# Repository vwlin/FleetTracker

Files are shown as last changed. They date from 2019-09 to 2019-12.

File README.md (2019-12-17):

# FleetTracker
Dugan's Dogs capstone project! Solar-powered vehicle tracking with real-time map visualization.

Setup instructions:
A and B necessary to complete setup

A. CCS Setup
1. Create new CCS project
2. In New CCS Project window, select MSP430F5529 for target and choose to create an empty project (without main.c)
3. In Project Explorer, right click on project, go to Add Files
4. Select relevant files and choose Link to Files (ensures compatibility with Git)

B. Adding "driverlib" folder
1. In Project Explorer, right click on project, go to Import > Import
2. In Import window, go to General > File System, then Next
3. Browse and select the directory (DirX) one step above driverlib folder, then OK
4. Dropdown DirX and check driverlib (not DirX), then Finish

C. Creating new files
1. Create file in local repo, but don't create it using CCS (i.e. use file explorer, terminal, etc)
2. Link to file in CCS (see A. 3-4)

TeraTerm download and Tips:
Download latest version of TeraTerm [here](https://ttssh2.osdn.jp/index.html.en).
To use TeraTerm with the firmware:
1. Open Tera Term and select Serial. Select the appropriate USB Serial Port for the port. Click OK.
2. If the device does not show up as a serial port, the proper drivers may not be installed and can be found [here](https://www.ftdichip.com/FTDrivers.htm).
3. Go to Setup > Serial Port. In the dropdown menu for Speed, select the appropriate baudrate. Click OK.
4. Go to Setup > Terminal and select Local echo. In the Coding-receive and Coding-transmit dropdown menus, select "UTF-8". Click OK.
5. TeraTerm is ready to be used

UI Setup
1. If using Windows, we recommend using Anaconda to install all Python packages, found here: https://www.anaconda.com/distribution/#windows
2. The following packages are required for our UI to display correctly:
* serial:      conda install -c anaconda pyserial
* folium:      conda install -c conda-forge folium
* matplotlib:  conda install -c conda-forge matplotlib
* selenium:    conda install -c conda-forge selenium
* pyautogui:   conda install -c conda-forge pyautogui
3. To run the program:
* open an Anaconda terminal
* cd into the project directory
* run in the terminal:
	* python main.py <COM#>

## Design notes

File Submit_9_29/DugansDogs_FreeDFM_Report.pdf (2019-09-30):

What FreeDFM found on your design

# Show Stoppers

## We Found None!

# Problems Automatically Fixed

Insufficient Silkscreen Line Width (494 violations) (https://www.freedfm.com/freedfm/0027733205411211/results/silkscreen_line_width.htm) | 1 (https://www.freedfm.com/freedfm/0027733205411211/results/silkscreen_line_width.htm#1) 2 (https://www.freedfm.com/freedfm/0027733205411211/results/silkscreen_line_width.htm#2) 3 (https://www.freedfm.com/freedfm/0027733205411211/results/silkscreen_line_width.htm#3) 4 (https://www.freedfm.com/freedfm/0027733205411211/results/silkscreen_line_width.htm#4) 5 (https://www.freedfm.com/freedfm/0027733205411211/results/silkscreen_line_width.htm#5)

Advanced
Circuits

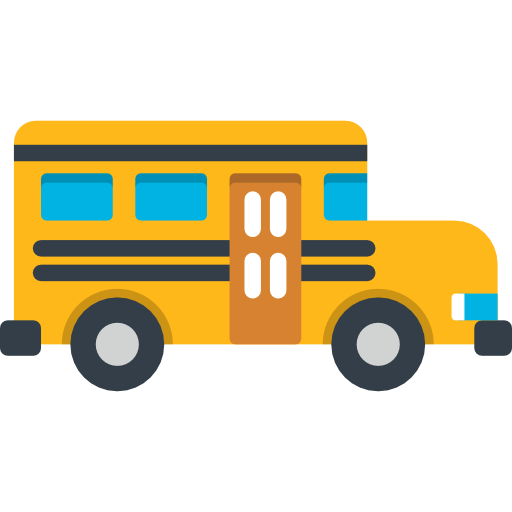
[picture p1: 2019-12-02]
UI/bus.png

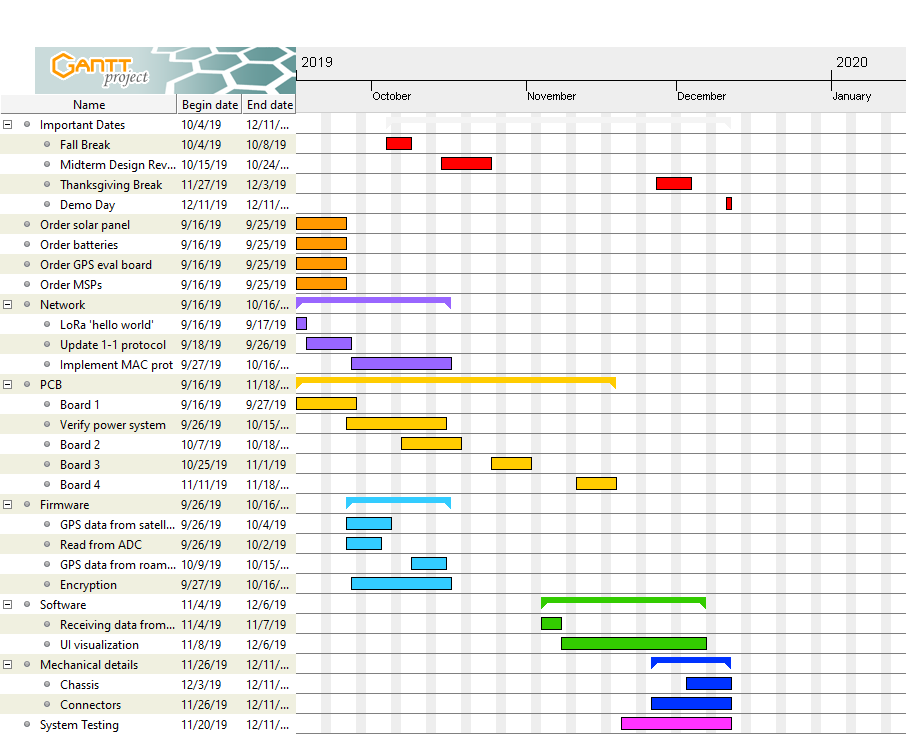
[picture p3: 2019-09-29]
Gantt Chart/CapstoneGantt.png

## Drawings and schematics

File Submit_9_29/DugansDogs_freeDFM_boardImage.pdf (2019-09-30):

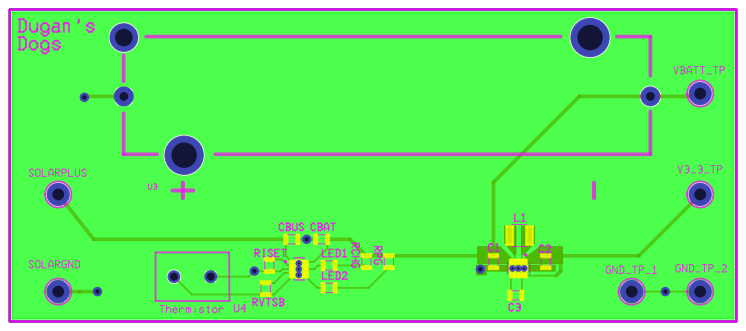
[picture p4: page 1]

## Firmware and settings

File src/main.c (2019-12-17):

#include <msp430.h>
#include <stdlib.h>
#include <string.h>
#include <stdio.h>
#include <stdint.h>

#include "SPI.h"
#include "LORA.h"
#include "test.h"
#include "protocol.h"
#include "UART.h"
#include "help.h"
#include "clock.h"
#include "configure.h"
#include "gps.h"
#include "timerA.h"

/* CHOOSE ONE
 *
 * ROAMING_NODE
 * HOME_NODE
 * TEST
 */

//#define ROAMING_NODE
#define HOME_NODE
//#define TEST

// TODO: move to protocol.h file somehow
uint16_t backoffSec[8] = {1, 2, 4, 8, 16, 32, 64, 128}; // Exponential back-off lookup table for MAC protocol, for a = 2 seconds

uint8_t year, month, day, hour, min, sec;
int32_t latitude, longitude;

void main(void){
    WDTCTL = WDTPW | WDTHOLD;   // Stop watchdog timer

    Configure_Clock();
    Configure_UART();
    Configure_SPI_LORA();
    Configure_LORA();

    #ifdef ROAMING_NODE
    Configure_SPI_GPS();
    Configure_GPS();
    Configure_TimerA();
    #endif

    unsigned char configPacket[28];
    unsigned char navPacket[8];

    // Construct data request and configuration packets for GPS
    ublox_configure_spi_port(configPacket);
    configure_ublox_poll(navPacket, 0x01, 0x07);

    unsigned char ublox_input_buffer[100];
    unsigned char payload[92];
    int i;

    #ifdef TEST
    volatile uint8_t passLORA = testLORA();
    #endif

    // Reset LoRa chip
    LORA_Reset();

    #ifndef TEST
    // Check for errors in the LoRa chip
    uint16_t errors = LORA_GetDeviceErrors();
    if(errors != 0){
        printf("\r\nErrors found. Restart the device.");
        while(1);
    }
    #endif

    // Configure communications
    LORA_SetStandby(STDBY_RC);
    LORA_SetPacketType(PACKET_TYPE_LORA);
    LORA_SetRfFrequency(CENTER_FREQUENCY); // Configurable in configure.h
    LORA_SetPaConfig(0x04, 0x07, PA_CONFIG_1262);
    LORA_SetTxParams(22, SET_RAMP_200U);
    LORA_SetModulationParams(0, 0, 0, SPREADING_FACTOR, CODING_RATE, LDR_OPT_ENABLE, BANDWIDTH); // Configurable in configure.h
    LORA_SetPacketParams(0, 0, 0, 0, 0, HEADER_MODE, IQ_MODE, PREAMBLE_LENGTH, PAYLOAD_LENGTH, CRC_ENABLE); // Configurable in configure.h
    LORA_SetBufferBaseAddress(0x00, 0x00); // Use all 256 bytes for the current mode
    LORA_SetCadParams(CAD_ON_8_SYMB, 25, 6, CAD_ONLY, 0); // Perform CAD operation, then return to STBY_RC mode

    // Set LoRa Sync word MSB and LSB
    uint8_t regData[2] = {0x14, 0x24};
    LORA_WriteRegister(0x0740, regData, 2);

    // Configure hardware
    LORA_SetRegulatorMode(REGULATOR_DCDC_LDO); // Use DC-DC regulator
    SET_ANT_SW; // Set RF switch to pass through TX output
    LORA_SetDIO2AsRfSwitchCtrl(DIO2_AS_SWITCH); // Set RF switch to pass through TX output

    #ifdef TEST
    volatile uint8_t passLORA = testLORA();

    // Select on of the following tests at a time
    //LORA_SetTxContinuousWave();
    LORA_SetTxInfinitePreamble();
    //volatile uint8_t passRF = testReceiveOneFrame();  // Select either this line or testTransmitOneFrame

    while(1){
        //testTransmitOneFrame();   // Select either this line or testReceiveOneFrame
    }
    #endif

    uint8_t data[PAYLOAD_LENGTH] = {0};
    uint8_t status = 0;

    // RDT protocol related variables
    uint8_t seqNumber[1] = {0}; // Start with a sequence number of 0

    // MAC protocol related variables
    uint16_t channelStatus;
    uint8_t numAttempts;

    while(1){
        #ifdef ROAMING_NODE
            // Fill variables from payload
            for(i = 0; i<92; i++){
                payload[i] = ublox_input_buffer[i + 6];
            }

            // Populate variables with bits from payload
            year = (uint8_t)(payload[4]) + (uint8_t)(payload[5] << 8);
            month = (uint8_t)payload[6];
            day = (uint8_t)payload[7];
            hour = (uint8_t)payload[8] - 5; // Subtract 5 to get our local time
            min = (uint8_t)payload[9];
            sec = (uint8_t)payload[10];
            longitude = ((int32_t) payload[27]) << 24 | ((int32_t) payload[26]) << 16 |
                    ((int32_t) payload[25]) << 8 | (int32_t) (payload[24]);
            latitude = ((int32_t) payload[31]) << 24 | ((int32_t) payload[30]) << 16 |
                            ((int32_t) payload[29]) << 8 | (int32_t) (payload[28]);

            // Clear input buffer
            for(i = 0; i<100; i++){
                ublox_input_buffer[i] = 0;
            }

            // Send configuration packet to GPS
            SPI_SendPacket_GPS(configPacket, 28);

            // Wait until data received is nonzero
            while(ublox_input_buffer[0] == 0) {
                SPI_ReceivePacket_GPS(ublox_input_buffer,100);
            }

            // Wait until data received starts with 0xB5 (UBX Protocol)
            while((ublox_input_buffer[0] != 0xb5)){

                // Send data request
                SPI_SendPacket_GPS(navPacket,8);
                for(i = 0; i<100; i++) ublox_input_buffer[i]=0;

                // Wait until data received is nonzero
                while(ublox_input_buffer[0] == 0) {
                    SPI_ReceivePacket_GPS(ublox_input_buffer,100);
               }
            }

            // Fill empty locations with zeros
            for(i = 0; i < PAYLOAD_LENGTH; i++){
                data[i] = 0;
            }

            // Fill payload, leaving first bit empty for sequence number
            data[0] = (uint8_t)((DEVICE_ID & 0x1FC0) >> 6);
            data[1] = (uint8_t)((DEVICE_ID & 0x003F) << 2);
            // Optional: data[1] | first 2 bits of ADC readings
            data[4] = (uint8_t)((latitude & 0xC0000000) >> 30); // Optional: OR with end of ADC readings
            data[5] = (uint8_t)((latitude & 0x3FC00000) >> 22);
            data[6] = (uint8_t)((latitude & 0x003FC000) >> 14);
            data[7] = (uint8_t)((latitude & 0x00003FC0) >> 6);  // In python, read latitude values and shift left 6
            data[8] = (uint8_t)((longitude & 0xFF000000) >> 24);
            data[9] = (uint8_t)((longitude & 0x00FF0000) >> 16);
            data[10] = (uint8_t)((longitude & 0x0000FF00) >> 8);
            data[11] = (uint8_t)(longitude & 0x000000C0); // In python, read longitude values and shift left 6
            data[11] |= (uint8_t)((day & 0x1F) << 1);
            data[11] |= (uint8_t)((month & 0x08) >> 3);
            data[12] = (uint8_t)((month & 0x07) << 5);
            data[12] |= (uint8_t)(hour & 0x1F);
            data[13] = (uint8_t)((min & 0x3F) << 2);
            data[13] |= (uint8_t)((sec & 0x30) >> 4);
            data[14] = (uint8_t)((sec & 0x0F) << 4);

            printf("\r\nDevice %d", DEVICE_ID);
            printf("\r\nPayload: ");
            for(i = 0; i < PAYLOAD_LENGTH; i++){
                printf("%x ", data[i]);
            }

            // Check for channel activity and repeat if activity detected
            numAttempts = 0;
            channelStatus = 0x0180;
            while( ( channelStatus & 0x0100) && (numAttempts <= GIVEUP_MAC) ){ // Repeat as long as CAD has been detected
                LORA_SetDioIrqParams(0x0180, 0x0000, 0x0000, 0x0000); // Enable CadDone and CadDetected IRQs
                LORA_SetCAD(); // Begin CAD
                while( !LORA_GetIrqStatus() ); // Poll CadDone IRQ
                channelStatus = LORA_GetIrqStatus(); // Check CadDetected IRQ
                LORA_ClearIrqStatus(0x0180); // Clear CadDone and CadDetected
                numAttempts++;
                if(channelStatus & 0x0100){ // If activity detected, wait
                    delay_s(backoffSec[numAttempts]);
                }
                // Print out results
                if(channelStatus & 0x0100)
                    printf("\r\nChannel activity detected, attempt %d", numAttempts);
                else
                    printf("\r\nNo channel activity detected, attempt %d", numAttempts);
            }

            // Proceed based on results of MAC checks
            if(numAttempts > GIVEUP_MAC){ // Activity detected multiple times in a row
                printf("\r\nGave up");
            }
            else if( !(channelStatus & 0x0100) ){ // No activity detected
                printf("\r\nSending data");
                status = Roamer_EstablishConnection(data, PAYLOAD_LENGTH, seqNumber);
            }

            // Sleep for sleepTime seconds
            // Enter LPM1 with SCLK on (SMCLKOFF = 0): ACLK and SCLK on, GPIO unchanged
            ENABLE_TIMER_INTERRUPT; // Enable timer for exiting sleep mode
            __bis_SR_register(LPM1_bits + GIE); // Keeps interrupts enabled, SMCLKOFF already set to 0
            DISABLE_TIMER_INTERRUPT;
        #endif

        #ifdef HOME_NODE
            uint8_t data[PAYLOAD_LENGTH] = {0};
            uint16_t deviceID;

            status = Home_WaitForConnection(data, PAYLOAD_LENGTH);

            deviceID = ((data[0] & 0x7F) << 6) + ((data[1] & 0xFC) >> 2);

            data[0] &= ~0x80; // Zero out sequence number

            // Send data to UART
            // printf("\r\nReceived from device %d:\r\n", deviceID); // Uncomment for testing with terminal
            for(i = 0; i < PAYLOAD_LENGTH; i++){
                printf("%x ", data[i]);
            }
            printf("\r\n");
        #endif

        if(status)
            printf("\r\nData transfer failed\r\n");
        else
            printf("\r\nData transfer success!\r\n");
    }
}

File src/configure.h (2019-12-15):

#ifndef CONFIGURE_H_
#define CONFIGURE_H_

/*
 * USER CONFIGURATIONS FOR DEVICE
 */
#define DEVICE_ID           35                   // Device ID, range: 0-8191

/*
 * USER CONFIGURATIONS FOR LORA
 */
#define CENTER_FREQUENCY    915000000           // Center frequency, units: Hz
#define SPREADING_FACTOR    LORA_SF12           // Spreading factor, options: LORA_SFx for x=5-12
#define CODING_RATE         LORA_CR_4_5         // Coding rate, options:LORA_CR_4_x for x=5-8
#define LDR_OPT_ENABLE      LORA_OPT_OFF        // Low data rate optimization, options: LORA_OPT_ON, LORA_OPT_OFF
#define BANDWIDTH           LORA_BW_500         // Bandwidth, options: LORA_BW_x for x=7, 10, 15, 20, 31, 41, 62, 125, 250, 500
#define HEADER_MODE         LORA_HT_IMPLICIT    // Header mode, options: LORA_HT_EXPLICIT, LORA_HT_IMPLICIT
#define IQ_MODE             LORA_IQ_STANDARD    // IQ mode, options: LORA_IQ_STANDARD,LORA_IQ_INVERTED
#define PREAMBLE_LENGTH     12                  // Preamble length, range: 10-65535
#define PAYLOAD_LENGTH      15                  // Payload length, range: 0-254
#define CRC_ENABLE          LORA_CRC_ON         // CRC enable, options: LORA_CRC_ON, LORA_CRC_OFF

#endif /* CONFIGURE_H_ */

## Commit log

2019-09-28 10-WSON footprint
2019-09-28 battery component
2019-09-28 Add Power Board 01
2019-09-28 Add Buck Boost
2019-09-28 Add Power and Ground Test Points
2019-09-29 remaining component footprints
2019-09-29 update footprints
2019-09-29 Add Team Name & Widen Board Outline
2019-09-29 Reduce trace clearances
2019-09-29 ACTUALLY Decrease Trace clearance
2019-09-30 add database info to resistor
2019-09-30 board pdfs
2019-09-30 Rotate Silkscreen for 2 Resistors
2019-09-30 board 1 sendout submission
2019-10-10 rf board initial schematic
2019-10-11 added base files from MountainHowler, gitignore for ccs items
2019-10-11 removed timer files
2019-10-11 rf schematic complete
2019-10-15 Add test points to LoRa Schematic
2019-10-15 Add files via upload
    added uart, 1x4, 1x8 headers to database
2019-10-15 Add signals for UART board
2019-10-15 Add UART signals w/ updated database
2019-10-15 Add USB to UART connector
2019-10-15 Add GPS connectors
2019-10-15 Add debug LEDs and UART test points
2019-10-16 schematic with footprints/parts info
2019-10-16 combined handshake and transceiving code into single protocol file, cleaned up dependency issues from deleted files
    [UART.c, main.c, protocol.h]
2019-10-17 board done?
    [LoRa Board - 3D-Info Bottom.gbr, LoRa Board - 3D-Info Top.gbr, LoRa Board - Board Outline.gbr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]
2019-10-23 VI Reads voltage
2019-10-24 Add VI to round ADC readings
2019-10-24 Add current and power calculations
2019-10-28 removed EEPROM from spi code
2019-10-29 giveup condition bug fixed
    [main.c]
2019-11-06 setting up gps spi
2019-11-07 testing UART
2019-11-07 fixed uart settings for 9600 baud rate
    [main.c]
2019-11-07 Add code to control GPS Chip Select pin
2019-11-07 Now properly assigning value to print buffer
2019-11-07 updated test one frame code
2019-11-09 implemented suggested implicit header timeout bug workaround for sf12 with implicit header mode
    [LORA.c, main.c]
2019-11-09 cleaned up workaround code, added helper function LORA_ResetTimeoutCounter in LORA c and h
    [LORA.c, LORA.h, main.c]
2019-11-09 adjusted payload to work with gps and adc data
2019-11-10 fixed battery charger
2019-11-10 printing something meaningful?
2019-11-14 Remove SPI waiting debug printf()
2019-11-21 sequence number fix started
    [main.c, protocol.h]
2019-11-26 Update LV for hall-effect sensor
2019-12-01 fixed minor bug with masking IRQ reg
    [main.c]
2019-12-02 fixed dev id location in packet; check dev id for every packet received
    [configure.h, main.c, protocol.h]
2019-12-02 fixed bug relating to filling dev id into packet
    [configure.h, main.c]
2019-12-02 send device ID in ACK and in handshake
2019-12-02 hanging problem with mac
    [configure.h]
2019-12-03 fixed bugs for putting gps data into packets
    [SPI.c, main.c]
2019-12-04 added some test code for testing gps wireless data transfer
2019-12-05 fixed bug and added delay to avoid mac loops
    [configure.h, main.c]
2019-12-15 removed unused LED files
2019-12-15 refactored timer and UART files
2019-12-16 updating spi comments
